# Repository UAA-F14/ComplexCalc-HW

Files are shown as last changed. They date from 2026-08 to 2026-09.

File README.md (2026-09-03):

# ComplexCalc — Hardware Version 🔌⚡

**A standalone embedded calculator for complex n×n linear systems (Ax=b)** — no PC required at runtime. Custom STM32F411 PCB with a 16-button keypad and an ILI9341 TFT display, built for electronics students and AC circuit analysis.

> [!NOTE]
> **Work in progress.** Firmware is functional (keypad input, TFT UI, Gauss-Jordan solver); the PCB is still being routed (some ADC connections are pending — see [Design](#-design-pcb)).

---

## 📁 Repository Structure

```
├── code/
│   └── 06ComplexCalcDasProject/   # STM32CubeIDE / CMake firmware project
│       ├── Core/
│       │   ├── Inc/               # ComplexGJ.h (solver), TFT_Screen.h, display_ui.h, ...
│       │   └── Src/                # SWComplexGJ.c (solver), TFT_Screen.c, display_ui.c, main.c, ...
│       └── Drivers/                # Vendored STM32 HAL + CMSIS (ST-generated, not project code)
├── design/
│   └── ComplexCalc/                # KiCad schematic + PCB (in progress)
└── README.md
```

The actual project logic lives in `Core/Inc` / `Core/Src`; everything under `Drivers/` is STM32CubeMX-generated boilerplate.

---

## 🎯 Overview

- **MCU:** STM32F411C(C/E)U (Cortex-M4, UFQFPN48) — the same chip used on "BlackPill" dev boards, but here on a custom PCB, you can use the minimum sistem or insert a blackpill in the socket, it works either way.
- **Display:** ILI9341 TFT over SPI.
- **Input:** 16-button matrix keypad (4×4), wired directly on the PCB.
- **Power:** coin-cell battery holder + AMS1117-3.3 LDO regulator.
- **Solver:** Gauss-Jordan elimination, single-precision (`float`) complex arithmetic, systems from 2×2 up to 4×4.

No serial terminal, USB host, or PC connection is needed to use the calculator — power it on, and the keypad + screen are the whole interface. (USB/SWD is only used to flash firmware.)

---

## 🚀 Build & Flash

**Using STM32CubeIDE (recommended):**
1. Open STM32CubeIDE.
2. File → Open Projects from File System.
3. Select `code/06ComplexCalcDasProject/`.
4. Build (`Ctrl+B`), then flash over USB/SWD (`Ctrl+Alt+X`).

**Using CMake + the ARM GCC toolchain (also supported by this project):**
```bash
cd code/06ComplexCalcDasProject
cmake --preset Debug      # or: Release
cmake --build --build-preset Debug
```
This uses the project's own `cmake/gcc-arm-none-eabi.cmake` toolchain file — you'll need `arm-none-eabi-gcc` and `ninja` installed.

---

## 🎮 Usage

On power-up, the screen prompts for the system size (`2`–`4`). From there:

| Input | Action |
|---|---|
| `0`–`9` | Enter digits (toggles between real/imaginary part) |
| `=` | Confirm entry / advance |
| `S` + `P` (combo) | Cycle display theme |

Once the full A matrix and b vector are entered, the solver runs on-device and the result is shown on screen — no PC needed.

---

## 🧮 Solver Details

- **Algorithm:** Gauss-Jordan elimination (`solve_complex_system` in `ComplexGJ.h`/`SWComplexGJ.c`).
- **Precision:** single-precision float, `EPSILON = 1e-7` for singularity checks.
- **Maximum size:** 4×4 (`N_MAX`), matching the keypad-driven size range (2–4).
- **Error handling:** returns `SOLVER_ERR_INVALID_SIZE` / `SOLVER_ERR_SINGULAR` for out-of-range sizes or singular matrices.

---

## 🖥️ Design (PCB)

KiCad project at `design/ComplexCalc/` — schematic + PCB for the keypad, MCU, TFT header, and power circuitry.

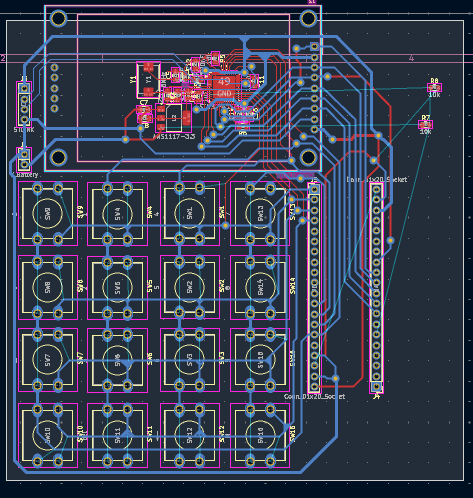
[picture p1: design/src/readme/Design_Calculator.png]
PCB routing in progress


*Routing in progress — some ADC-related connections are still pending. A rendered board image will replace this screenshot once the layout is finished.*

A datasheet-vs-schematic power supply review (VCAP sizing, VBAT, NRST, HSE crystal value) is available at [`docs/ComplexCalc-HW_power_supply_review_en.pdf`](docs/ComplexCalc-HW_power_supply_review_en.pdf) ([Spanish version](docs/ComplexCalc-HW_power_supply_review.pdf)).

---

## 🤝 Contributing

1. Firmware changes go in `code/06ComplexCalcDasProject/Core/`.
2. PCB changes go in `design/ComplexCalc/` (KiCad 8+).
3. Open a PR against this repo.

## 📞 Issues

Report bugs or hardware questions via this repo's [Issues](https://github.com/UAA-F14/ComplexCalc-HW/issues).

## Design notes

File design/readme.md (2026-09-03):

# Design

## Collaborators

- **das** — base layout and initial design.
- **robertoloro** — routing the rest of the board.
- **IKGB** — checking and validating the minimum system.

# Logfile
## 8-28

Pending to connect multiple veins of minimum system.

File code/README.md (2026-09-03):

# Code

Firmware for the STM32F411CEUx (`06ComplexCalcDasProject/`, STM32CubeIDE / CMake project).

## Collaborators

- **das** — wrote the firmware (keypad input, TFT UI, Gauss-Jordan solver).

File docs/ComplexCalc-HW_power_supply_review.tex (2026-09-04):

\documentclass[11pt]{article}
\usepackage[margin=2.5cm]{geometry}
\usepackage[utf8]{inputenc}
\usepackage[T1]{fontenc}
\usepackage{graphicx}
\usepackage{booktabs}
\usepackage{longtable}
\usepackage{xcolor}
\usepackage{hyperref}
\usepackage{siunitx}
\usepackage{caption}
\hypersetup{colorlinks=false, pdfborder={0 0 0}}

\renewcommand{\figurename}{Figura}
\renewcommand{\tablename}{Tabla}
\renewcommand{\contentsname}{Índice}

\definecolor{okgreen}{RGB}{0,120,60}
\definecolor{warnred}{RGB}{180,30,30}
\definecolor{sugamber}{RGB}{170,110,0}

\title{ComplexCalc-HW — Revisión del esquema de alimentación}
\author{}
\date{}

\begin{document}
\maketitle
\vspace{-1.3cm}

\section{Propósito}

Este documento resume los requisitos oficiales de alimentación del
STM32F411CEUx (datasheet DocID026289 Rev.\,7, ST\-Microelectronics) para el
paquete \textbf{UFQFPN48}, y los compara contra lo que actualmente está
routeado en \texttt{design/\allowbreak ComplexCalc/\allowbreak
ComplexCalc.kicad\_sch} del repositorio
\texttt{UAA-F14/\allowbreak ComplexCalc-HW}. Todas las figuras y tablas de referencia son
capturas directas del datasheet oficial.

\section{Pinout real: UFQFPN48}

La Figura~\ref{fig:pinout} (Figura~10 del datasheet, página~34) muestra la
asignación exacta de pines del paquete que se usa en esta placa. De ahí se
confirma:

\begin{itemize}
  \item \textbf{3 pines VDD}: 24, 36, 48
  \item \textbf{3 pines VSS}: 23, 35, 47
  \item \textbf{1 solo pin VCAP\_1} (pin 22) — este paquete \emph{no} trae
        VCAP\_2 (esa señal solo existe en LQFP100 y UFBGA100)
  \item VBAT: pin 1
  \item VDDA/VREF+: pin 9 · VSSA/VREF-: pin 8
  \item NRST: pin 7 · BOOT0: pin 44
\end{itemize}

\begin{figure}[h]
  \centering
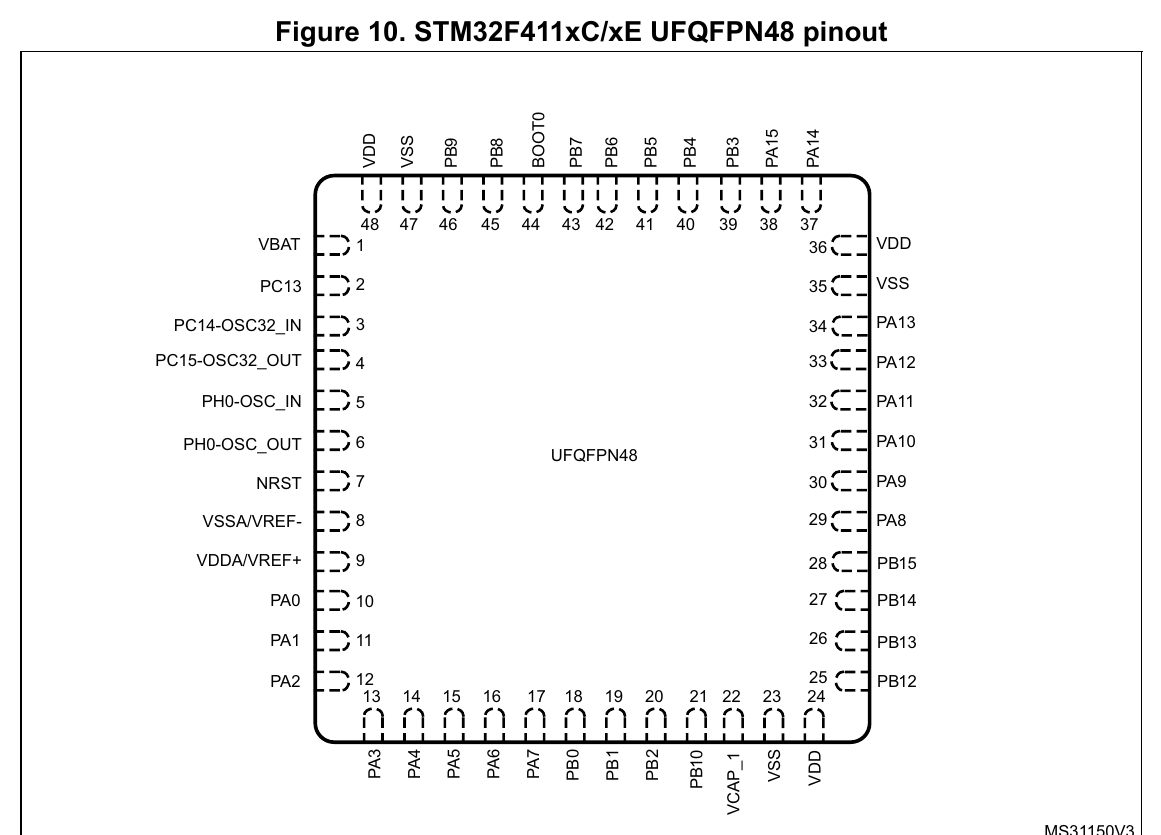
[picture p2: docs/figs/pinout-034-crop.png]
  
  \caption{Pinout UFQFPN48 — Figura 10, datasheet STM32F411xC/xE, pág.~34}
  \label{fig:pinout}
\end{figure}

\clearpage
\section{Esquema oficial de alimentación}

La Figura~\ref{fig:powerscheme} (Figura~17, Sección 6.1.6, página~59) es el
esquema de referencia de ST para el desacoplo de cada rama de alimentación.

\begin{figure}[h]
  \centering
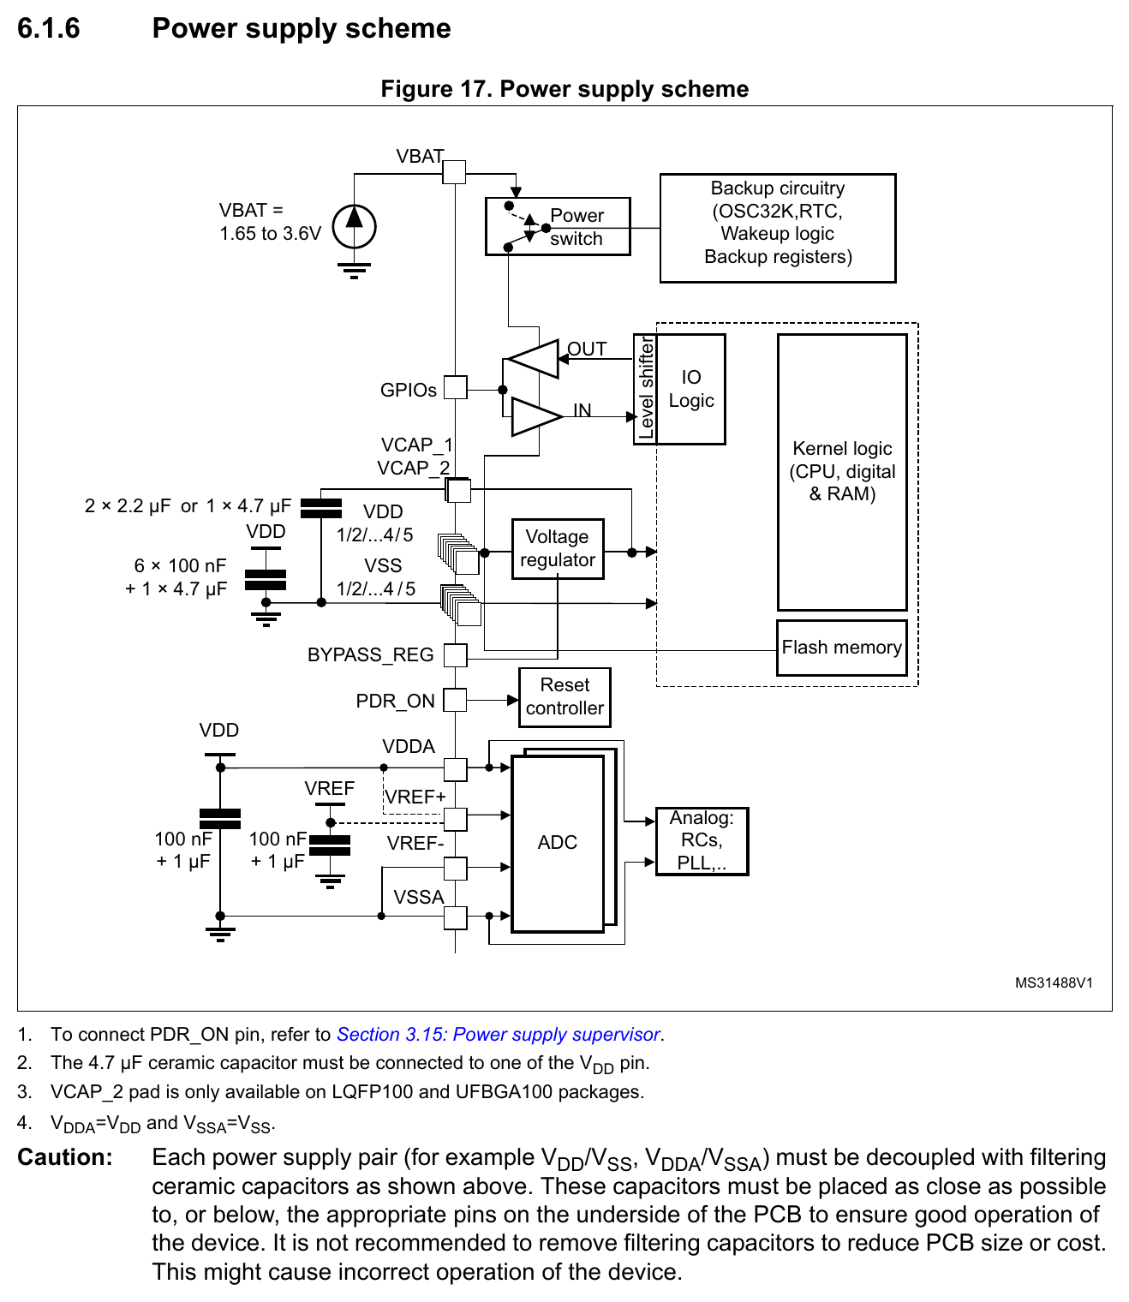
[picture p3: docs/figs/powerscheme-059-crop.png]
  
  \caption{Power supply scheme — Figura 17, Sección 6.1.6, pág.~59}
  \label{fig:powerscheme}
\end{figure}

\newpage
\section{Capacitor de VCAP para paquetes de un solo pin}

La Tabla~\ref{fig:vcaptable} (Tabla~16, Sección 6.3.2, página~65) da el valor
exacto que aplica específicamente cuando el paquete solo trae un pin VCAP
(nuestro caso).

\begin{figure}[h]
  \centering
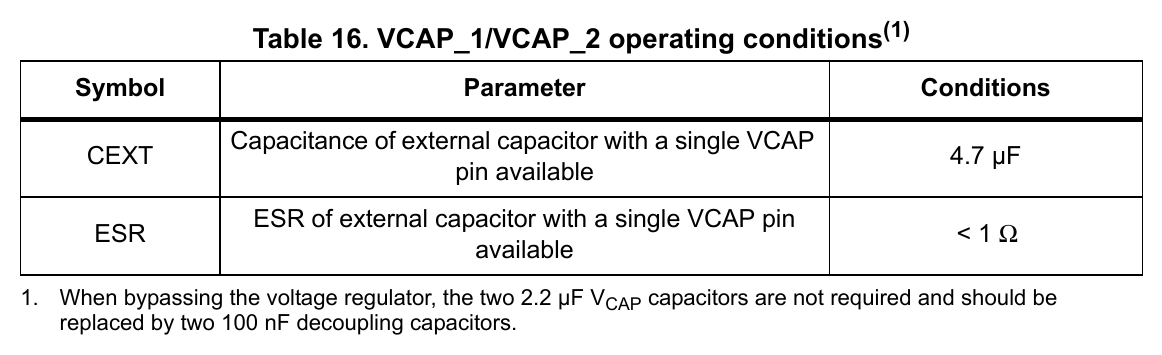
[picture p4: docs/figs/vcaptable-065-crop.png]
  
  \caption{VCAP\_1/VCAP\_2 operating conditions — Tabla 16, Sección 6.3.2, pág.~65}
  \label{fig:vcaptable}
\end{figure}

\section{Resumen: valores requeridos por pin}

\begin{longtable}{p{3.2cm}p{4.5cm}p{6cm}}
\toprule
\textbf{Pin(es)} & \textbf{Capacitor(es) requerido(s)} & \textbf{Fuente} \\
\midrule
\endhead
VDD / VSS (pines 24/23, 36/35, 48/47) &
  100\,nF por cada par VDD/VSS (3 en total) + 1$\times$4.7\,µF en cualquiera
  de los VDD &
  Figura~17, nota~2 \\
VCAP\_1 (pin 22) $\rightarrow$ GND &
  \textbf{4.7\,µF cerámico, ESR $<$ 1\,$\Omega$} (paquete de un solo VCAP) &
  Tabla~16, Sección~6.3.2 \\
VDDA/VREF+ (pin 9) $\leftrightarrow$ VSSA/VREF- (pin 8) &
  100\,nF + 1\,µF (un solo par: en este paquete VDDA y VREF+ comparten pin) &
  Figura~17 \\
VBAT (pin 1) &
  100\,nF, o conexión directa a VDD si no se usa batería de respaldo &
  Figura~17 \\
NRST (pin 7) &
  Ya trae pull-up interno — capacitor externo (100\,nF, opcional) solo
  mejora inmunidad a EMI, no es obligatorio &
  Tabla~7 (leyenda NRST) \\
BOOT0 (pin 44) &
  Sin bias interno — resistencia externa (típico 10\,k$\Omega$ pull-down
  para bootear de flash) &
  Sección 3.13 ``Boot modes'' \\
\bottomrule
\end{longtable}

\clearpage
\section{Comparación contra lo routeado en el esquemático real}

Extraído del netlist de \texttt{ComplexCalc.kicad\_sch} (exportado con
\texttt{kicad-cli}) el 2 de septiembre de 2026.

\begin{longtable}{p{3.5cm}p{3.2cm}p{3.2cm}p{4cm}}
\toprule
\textbf{Punto revisado} & \textbf{Requerido} & \textbf{En el esquemático} & \textbf{Veredicto} \\
\midrule
\endhead
VCAP\_1 (C14) & 4.7\,µF, ESR$<$1$\Omega$ & \textbf{2.2\,µF} &
  \textcolor{warnred}{\textbf{Por debajo del valor requerido}} — 2.2\,µF es el
  valor para paquetes con \emph{dos} pines VCAP, no uno solo. \\
VBAT (pin 1) & Atado a batería o a VDD & \textbf{Sin conexión (net aislada)} &
  \textcolor{warnred}{\textbf{Flotando}} — no está ni en el net de 3.3V ni tiene
  capacitor. \\
VDD/VSS (3 pares) & 3$\times$100\,nF + 1 bulk & C10, C11, C12 (100\,nF c/u)
  + C13 (1\,µF) + C8 (22\,µF) & \textcolor{okgreen}{Cumple} — bulk incluso más
  grande de lo mínimo pedido. \\
VDDA/VREF+ (pin 9) & 100\,nF + 1\,µF local & Mismo net de 3.3\,V que VDD,
  con C13 (1\,µF) presente & \textcolor{okgreen}{Cumple eléctricamente} — no se
  pudo verificar cercanía física del capacitor al pin desde el esquemático
  (revisar en el layout). \\
NRST & Pull-up interno ya suficiente; cap.\ típico 100\,nF & R4 (10\,k$\Omega$
  externo, redundante) + C9 (\textbf{1\,µF}, no 100\,nF) &
  \textcolor{sugamber}{\textbf{Sugerido bajar a 100\,nF}} — no es un error
  (sigue siendo funcional), pero 1\,µF alarga el tiempo de reset más de lo
  necesario. Confirmado contra el esquemático real del BlackPill (WeAct
  Studio): su circuito de reset usa exactamente \textbf{100\,nF} en el mismo
  nodo. \\
BOOT0 (R5) & Pull-down $\sim$10\,k$\Omega$ & 10\,k$\Omega$ &
  \textcolor{okgreen}{Correcto} \\
BOOT1/PB2 (R6) & Definir nivel & 10\,k$\Omega$ pull &
  \textcolor{okgreen}{Correcto} \\
Cristal HSE (Y1) & Coincidir con \texttt{RCC.HSE\_VALUE} en firmware &
  Y1 = \textbf{8\,MHz} físico, pero el \texttt{.ioc} tiene
  \texttt{HSE\_VALUE=25000000} & \textcolor{warnred}{\textbf{Revisar}} — si el
  firmware llega a habilitar HSE, el árbol de reloj debe recalcularse para
  8\,MHz, no 25\,MHz. \\
Regulador (U2) & --- & \textbf{AMS1117-3.3} (no NCP1117-3.3) &
  Nota de documentación: corregido en el README del repo. \\
\bottomrule
\end{longtable}

\section{Acciones recomendadas}

\begin{enumerate}
  \item Cambiar C14 de 2.2\,µF a \textbf{4.7\,µF} en VCAP\_1.
        \textcolor{okgreen}{\textbf{[Hecho]}} --- verificado en el netlist
        actual del esquemático: C14 = 4.7\,µF.
  \item Conectar VBAT (pin 1) a la red de 3.3\,V (o dejar un footprint de
        100\,nF si en el futuro se agrega batería de respaldo real para el
        RTC).
        \textcolor{okgreen}{\textbf{[Hecho]}} --- verificado: VBAT (U3
        pin~1) ahora está en el net \texttt{3.3V}.
  \item Bajar C9 (NRST) de 1\,µF a \textbf{100\,nF} — valor de libro y el que
        usa el BlackPill real de referencia en el mismo nodo.
        \textcolor{okgreen}{\textbf{[Hecho]}} --- verificado: C9 = 100\,nF.
  \item Antes de habilitar el HSE en firmware, corregir
        \texttt{RCC.HSE\_VALUE} a 8\,MHz en el \texttt{.ioc} y regenerar el
        árbol de reloj en STM32CubeMX.
  \item Verificar en el layout físico (no solo el esquemático) que los
        capacitores de VDD/VDDA queden lo más cerca posible de sus pines
        respectivos, dado que la capa inferior ya está ocupada por el
        teclado matricial.
\end{enumerate}

\end{document}

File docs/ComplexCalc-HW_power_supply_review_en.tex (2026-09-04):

\documentclass[11pt]{article}
\usepackage[margin=2.5cm]{geometry}
\usepackage[utf8]{inputenc}
\usepackage[T1]{fontenc}
\usepackage{graphicx}
\usepackage{booktabs}
\usepackage{longtable}
\usepackage{xcolor}
\usepackage{hyperref}
\usepackage{siunitx}
\usepackage{caption}
\hypersetup{colorlinks=false, pdfborder={0 0 0}}

\definecolor{okgreen}{RGB}{0,120,60}
\definecolor{warnred}{RGB}{180,30,30}
\definecolor{sugamber}{RGB}{170,110,0}

\title{ComplexCalc-HW --- Power Supply Review}
\author{}
\date{}

\begin{document}
\maketitle
\vspace{-1.3cm}

\section{Purpose}

This document summarizes the official power supply requirements of the
STM32F411CEUx (datasheet DocID026289 Rev.\,7, ST\-Microelectronics) for the
\textbf{UFQFPN48} package, and compares them against what is currently
routed in \texttt{design/\allowbreak ComplexCalc/\allowbreak
ComplexCalc.kicad\_sch} of the \texttt{UAA-F14/\allowbreak ComplexCalc-HW}
repository. All reference figures and tables are direct captures from the
official datasheet.

\section{Actual pinout: UFQFPN48}

Figure~\ref{fig:pinout} (Figure~10 of the datasheet, page~34) shows the
exact pin assignment of the package used on this board. From it we
confirm:

\begin{itemize}
  \item \textbf{3 VDD pins}: 24, 36, 48
  \item \textbf{3 VSS pins}: 23, 35, 47
  \item \textbf{Only 1 VCAP\_1 pin} (pin 22) --- this package does
        \emph{not} bring out VCAP\_2 (that signal only exists on the
        LQFP100 and UFBGA100 packages)
  \item VBAT: pin 1
  \item VDDA/VREF+: pin 9 · VSSA/VREF-: pin 8
  \item NRST: pin 7 · BOOT0: pin 44
\end{itemize}

\begin{figure}[h]
  \centering
  
  \caption{UFQFPN48 pinout --- Figure 10, STM32F411xC/xE datasheet, p.~34}
  \label{fig:pinout}
\end{figure}

\clearpage
\section{Official power supply scheme}

Figure~\ref{fig:powerscheme} (Figure~17, Section 6.1.6, page~59) is ST's
reference scheme for decoupling each power supply branch.

\begin{figure}[h]
  \centering
  
  \caption{Power supply scheme --- Figure 17, Section 6.1.6, p.~59}
  \label{fig:powerscheme}
\end{figure}

\newpage
\section{VCAP capacitor for single-pin packages}

Table~\ref{fig:vcaptable} (Table~16, Section 6.3.2, page~65) gives the
exact value that applies specifically when the package brings out only one
VCAP pin (our case).

\begin{figure}[h]
  \centering
  
  \caption{VCAP\_1/VCAP\_2 operating conditions --- Table 16, Section 6.3.2, p.~65}
  \label{fig:vcaptable}
\end{figure}

\section{Summary: required values per pin}

\begin{longtable}{p{3.2cm}p{4.5cm}p{6cm}}
\toprule
\textbf{Pin(s)} & \textbf{Required capacitor(s)} & \textbf{Source} \\
\midrule
\endhead
VDD / VSS (pins 24/23, 36/35, 48/47) &
  100\,nF per VDD/VSS pair (3 total) + 1$\times$4.7\,µF on any of the
  VDD pins &
  Figure~17, note~2 \\
VCAP\_1 (pin 22) $\rightarrow$ GND &
  \textbf{4.7\,µF ceramic, ESR $<$ 1\,$\Omega$} (single-VCAP package) &
  Table~16, Section~6.3.2 \\
VDDA/VREF+ (pin 9) $\leftrightarrow$ VSSA/VREF- (pin 8) &
  100\,nF + 1\,µF (single pair: on this package VDDA and VREF+ share a
  pin) &
  Figure~17 \\
VBAT (pin 1) &
  100\,nF, or a direct connection to VDD if no backup battery is used &
  Figure~17 \\
NRST (pin 7) &
  Already has an internal pull-up --- an external capacitor (100\,nF,
  optional) only improves EMI immunity, it is not mandatory &
  Table~7 (NRST legend) \\
BOOT0 (pin 44) &
  No internal bias --- external resistor (typ. 10\,k$\Omega$ pull-down
  to boot from flash) &
  Section 3.13 ``Boot modes'' \\
\bottomrule
\end{longtable}

\clearpage
\section{Comparison against the actual schematic}

Extracted from the \texttt{ComplexCalc.kicad\_sch} netlist (exported with
\texttt{kicad-cli}) on September 2, 2026.

\begin{longtable}{p{3.5cm}p{3.2cm}p{3.2cm}p{4cm}}
\toprule
\textbf{Checked item} & \textbf{Required} & \textbf{In the schematic} & \textbf{Verdict} \\
\midrule
\endhead
VCAP\_1 (C14) & 4.7\,µF, ESR$<$1$\Omega$ & \textbf{2.2\,µF} &
  \textcolor{warnred}{\textbf{Below the required value}} --- 2.2\,µF is
  the value for packages with \emph{two} VCAP pins, not a single one. \\
VBAT (pin 1) & Tied to battery or to VDD & \textbf{Unconnected (isolated
  net)} & \textcolor{warnred}{\textbf{Floating}} --- it is neither on the
  3.3\,V net nor does it have a capacitor. \\
VDD/VSS (3 pairs) & 3$\times$100\,nF + 1 bulk & C10, C11, C12 (100\,nF
  each) + C13 (1\,µF) + C8 (22\,µF) &
  \textcolor{okgreen}{Meets the requirement} --- bulk capacitance is even
  larger than the minimum required. \\
VDDA/VREF+ (pin 9) & 100\,nF + 1\,µF local & Same 3.3\,V net as VDD, with
  C13 (1\,µF) present & \textcolor{okgreen}{Electrically compliant} ---
  physical proximity of the capacitor to the pin could not be verified
  from the schematic (check the layout). \\
NRST & Internal pull-up already sufficient; typ.\ cap.\ 100\,nF & R4
  (10\,k$\Omega$ external, redundant) + C9 (\textbf{1\,µF}, not 100\,nF) &
  \textcolor{sugamber}{\textbf{Suggest lowering to 100\,nF}} --- not an
  error (it is still functional), but 1\,µF extends the reset time more
  than necessary. Confirmed against the actual BlackPill schematic (WeAct
  Studio): its reset circuit uses exactly \textbf{100\,nF} at the same
  node. \\
BOOT0 (R5) & $\sim$10\,k$\Omega$ pull-down & 10\,k$\Omega$ &
  \textcolor{okgreen}{Correct} \\
BOOT1/PB2 (R6) & Define level & 10\,k$\Omega$ pull &
  \textcolor{okgreen}{Correct} \\
HSE crystal (Y1) & Must match \texttt{RCC.HSE\_VALUE} in firmware &
  Y1 = \textbf{8\,MHz} physically, but the \texttt{.ioc} has
  \texttt{HSE\_VALUE=25000000} & \textcolor{warnred}{\textbf{Review}} ---
  if the firmware ever enables HSE, the clock tree must be recalculated
  for 8\,MHz, not 25\,MHz. \\
Regulator (U2) & --- & \textbf{AMS1117-3.3} (not NCP1117-3.3) &
  Documentation note: corrected in the repo's README. \\
\bottomrule
\end{longtable}

\section{Recommended actions}

\begin{enumerate}
  \item Change C14 from 2.2\,µF to \textbf{4.7\,µF} on VCAP\_1.
        \textcolor{okgreen}{\textbf{[Done]}} --- verified in the current
        schematic netlist: C14 = 4.7\,µF.
  \item Connect VBAT (pin 1) to the 3.3\,V rail (or leave a 100\,nF
        footprint if a real backup battery for the RTC is added in the
        future).
        \textcolor{okgreen}{\textbf{[Done]}} --- verified: VBAT (U3 pin~1)
        is now on the \texttt{3.3V} net.
  \item Lower C9 (NRST) from 1\,µF to \textbf{100\,nF} --- the textbook
        value, and the one used by the actual reference BlackPill at the
        same node.
        \textcolor{okgreen}{\textbf{[Done]}} --- verified: C9 = 100\,nF.
  \item Before enabling HSE in firmware, correct \texttt{RCC.HSE\_VALUE}
        to 8\,MHz in the \texttt{.ioc} and regenerate the clock tree in
        STM32CubeMX.
  \item Verify on the physical layout (not just the schematic) that the
        VDD/VDDA capacitors are placed as close as possible to their
        respective pins, since the bottom layer is already occupied by
        the matrix keypad.
\end{enumerate}

\end{document}

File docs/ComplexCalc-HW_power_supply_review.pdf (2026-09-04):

## ComplexCalc-HW — Revisión del esquema de alimentación

### 1 Propósito

Este documento resume los requisitos oficiales de alimentación del STM32F411CEUx (datasheet DocID026289 Rev. 7, STMicroelectronics) para el paquete UFQFPN48, y los compara contra lo que actualmente está routeado en design/ComplexCalc/ComplexCalc.kicad_sch del repositorio UAA-F14/ ComplexCalc-HW. Todas las figuras y tablas de referencia son capturas directas del datasheet oficial.

### 2 Pinout real: UFQFPN48

La Figura 1 (Figura 10 del datasheet, página 34) muestra la asignación exacta de pines del paquete que se usa en esta placa. De ahí se confirma:

- 3 pines VDD: 24, 36, 48
- 3 pines VSS: 23, 35, 47
- 1 solo pin VCAP_1 (pin 22) — este paquete no trae VCAP_2 (esa señal solo existe en LQFP100 y UFBGA100)
- VBAT: pin 1
- VDDA/VREF+: pin 9 · VSSA/VREF-: pin 8
- NRST: pin 7 · BOOT0: pin 44


Figura 1: Pinout UFQFPN48 — Figura 10, datasheet STM32F411xC/xE, pág. 34

### 3 Esquema oficial de alimentación

La Figura 2 (Figura 17, Sección 6.1.6, página 59) es el esquema de referencia de ST para el desacoplo de cada rama de alimentación.


Figura 2: Power supply scheme — Figura 17, Sección 6.1.6, pág. 59

### 4 Capacitor de VCAP para paquetes de un solo pin

La Tabla 3 (Tabla 16, Sección 6.3.2, página 65) da el valor exacto que aplica específicamente cuando el paquete solo trae un pin VCAP (nuestro caso).

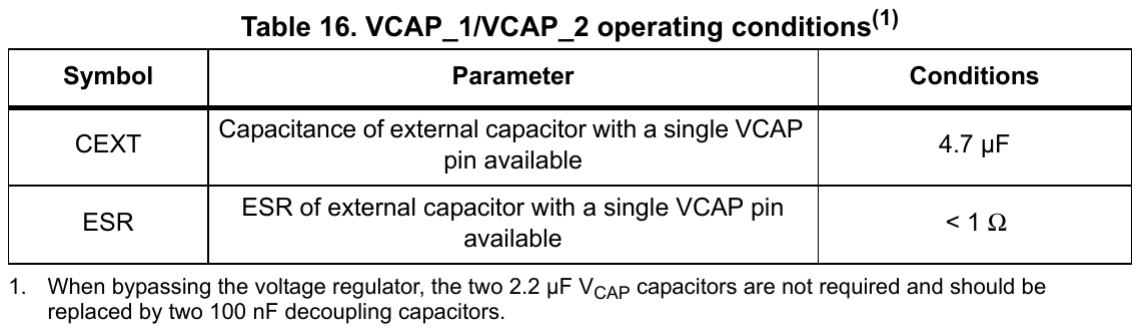
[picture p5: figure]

Figura 3: VCAP_1/VCAP_2 operating conditions — Tabla 16, Sección 6.3.2, pág. 65

### 5 Resumen: valores requeridos por pin

Pin(es) | Capacitor(es) | re-
querido(s)

Fuente

VDD / VSS (pines
24/23, | 36/35,
48/47)
100 nF | por | cada | par
VDD/VSS (3 en total) +
1×4.7 µF en cualquiera de
los VDD

Figura 17, nota 2

VCAP_1 (pin 22)
→ GND

### 4.7 µF cerámico, ESR < 1 Ω (paquete de un solo

VCAP)

Tabla 16, Sección 6.3.2

VDDA/VREF+
(pin | 9) | ↔
VSSA/VREF-
(pin 8)

100 nF + 1 µF (un solo par: en este paquete VDDA y
VREF+ comparten pin)

Figura 17

VBAT (pin 1) | 100 nF, o conexión directa a VDD si no se usa batería de respaldo
Figura 17
NRST (pin 7) | Ya trae pull-up interno — capacitor externo (100 nF, opcional) solo mejora in- munidad a EMI, no es obli- gatorio

Tabla 7 (leyenda NRST)

BOOT0 (pin 44) Sin bias interno — resisten- cia externa (típico 10 kΩ pull-down para bootear de flash)Sección 3.13 “Boot modes”

### 6 Comparación contra lo routeado en el esquemático real

Extraído del netlist de ComplexCalc.kicad_sch (exportado con kicad-cli) el 2 de septiembre de 2026.

Punto revisado | Requerido | En | el | es-
quemático

Veredicto

VCAP_1 (C14) | 4.7 µF, ESR<1Ω | 2.2 µF | Por debajo del valor
requerido — 2.2 µF es
el valor para paquetes
con dos pines VCAP, no
uno solo.
VBAT (pin 1) | Atado a batería o a
| VDD
Sin | conexión
(net aislada)

Flotando — no está ni
en el net de 3.3V ni tiene capacitor.
VDD/VSS (3 pares) | 3×100 nF + 1 bulk | C10, | C11, | C12
| | (100 nF | c/u) | +
C13 (1 µF) + C8
| | (22 µF)

Cumple — bulk incluso
más grande de lo mínimo pedido.

VDDA/VREF+ (pin
9)

100 nF + 1 µF local Mismo net de 3.3 V que VDD, con C13
(1 µF) presente

Cumple eléctricamente
— no se pudo verificar
cercanía física del capacitor al pin desde el
esquemático (revisar en
el layout).
NRST | Pull-up | interno
| ya suficiente; cap.
| típico 100 nF

R4 (10 kΩ externo,
redundante) + C9
(1 µF, no 100 nF)
Sugerido | bajar | a
100 nF — no es un
error | (sigue | siendo
funcional), pero 1 µF
alarga el tiempo de reset más de lo necesario.
Confirmado | contra
el | esquemático | real
del BlackPill (WeAct
Studio): su circuito de
reset usa exactamente
100 nF en el mismo
nodo.
BOOT0 (R5) | Pull-down ∼10 kΩ | 10 kΩ | Correcto
BOOT1/PB2 (R6) | Definir nivel | 10 kΩ pull | Correcto
Cristal HSE (Y1) | Coincidir | con
| RCC.HSE_VALUE en
| firmware
Y1 | = | 8 MHz
| | físico, | | pero
| | el | .ioc | tiene
HSE_VALUE=25000000
Revisar | — | si | el
firmware llega a habilitar HSE, el árbol de
reloj debe recalcularse
para 8 MHz, no 25 MHz.

Punto revisado | Requerido | En | el | es-
quemático

Veredicto

Regulador (U2) | — | AMS1117-3.3
(no NCP1117-3.3)

Nota de documentación:
corregido | en | el
README del repo.

### 7 Acciones recomendadas

1. Cambiar C14 de 2.2 µF a 4.7 µF en VCAP_1. [Hecho] — verificado en el netlist actual del esquemático: C14 = 4.7 µF.
2. Conectar VBAT (pin 1) a la red de 3.3 V (o dejar un footprint de 100 nF si en el futuro se agrega batería de respaldo real para el RTC). [Hecho] — verificado: VBAT (U3 pin 1) ahora está en el net 3.3V.
3. Bajar C9 (NRST) de 1 µF a 100 nF — valor de libro y el que usa el BlackPill real de referencia en el mismo nodo. [Hecho] — verificado: C9 = 100 nF.
4. Antes de habilitar el HSE en firmware, corregir RCC.HSE_VALUE a 8 MHz en el .ioc y regenerar el árbol de reloj en STM32CubeMX.
5. Verificar en el layout físico (no solo el esquemático) que los capacitores de VDD/VDDA queden lo más cerca posible de sus pines respectivos, dado que la capa inferior ya está ocupada por el teclado matricial.

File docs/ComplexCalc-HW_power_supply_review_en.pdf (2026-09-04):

## ComplexCalc-HW — Power Supply Review

### 1 Purpose

This document summarizes the official power supply requirements of the STM32F411CEUx (datasheet DocID026289 Rev. 7, STMicroelectronics) for the UFQFPN48 package, and compares them against
what is currently routed in design/ComplexCalc/ComplexCalc.kicad_sch of the UAA-F14/ComplexCalc-HW repository. All reference figures and tables are direct captures from the official datasheet.

### 2 Actual pinout: UFQFPN48

Figure 1 (Figure 10 of the datasheet, page 34) shows the exact pin assignment of the package used on this board. From it we confirm:

- 3 VDD pins: 24, 36, 48
- 3 VSS pins: 23, 35, 47
- Only 1 VCAP_1 pin (pin 22) — this package does not bring out VCAP_2 (that signal only exists on the LQFP100 and UFBGA100 packages)
- VBAT: pin 1
- VDDA/VREF+: pin 9 · VSSA/VREF-: pin 8
- NRST: pin 7 · BOOT0: pin 44


Figure 1: UFQFPN48 pinout — Figure 10, STM32F411xC/xE datasheet, p. 34

### 3 Official power supply scheme

Figure 2 (Figure 17, Section 6.1.6, page 59) is ST’s reference scheme for decoupling each power supply branch.


Figure 2: Power supply scheme — Figure 17, Section 6.1.6, p. 59

### 4 VCAP capacitor for single-pin packages

Table 3 (Table 16, Section 6.3.2, page 65) gives the exact value that applies specifically when the package brings out only one VCAP pin (our case).


Figure 3: VCAP_1/VCAP_2 operating conditions — Table 16, Section 6.3.2, p. 65

### 5 Summary: required values per pin

Pin(s) | Required capacitor(s) | Source

VDD / VSS (pins
24/23, | 36/35,
48/47) | 100 nF per VDD/VSS pair (3 total) + 1×4.7 µF on any of the VDD pins
Figure 17, note 2

VCAP_1 (pin 22)
→ GND

### 4.7 µF ceramic, ESR

< 1 Ω (single-VCAP package)

Table 16, Section 6.3.2

VDDA/VREF+
(pin | 9) | ↔
VSSA/VREF-
(pin 8)

100 nF + 1 µF (single pair: on this package VDDA and
VREF+ share a pin)

Figure 17

VBAT (pin 1) | 100 nF, or a direct connec- tion to VDD if no backup battery is used
Figure 17
NRST (pin 7) | Already has an internal pull-up — an external ca- pacitor (100 nF, optional) only improves EMI immu- nity, it is not mandatory

Table 7 (NRST legend)

BOOT0 (pin 44) No internal bias — external resistor (typ. 10 kΩ pull- down to boot from flash) Section 3.13 “Boot modes”

### 6 Comparison against the actual schematic

Extracted from the ComplexCalc.kicad_sch netlist (exported with kicad-cli) on September 2, 2026.

Checked item | Required | In the schematic | Verdict
VCAP_1 (C14) | 4.7 µF, ESR<1Ω | 2.2 µF | Below the required
value — 2.2 µF is the
value for packages with
two VCAP pins, not a
single one.
VBAT (pin 1) | Tied to battery or to VDD
Unconnected
(isolated net)

Floating — it is neither on the 3.3 V net nor
does it have a capacitor.
VDD/VSS (3 pairs) | 3×100 nF + 1 bulk | C10, | C11, | C12
(100 nF each) +
C13 (1 µF) + C8
| | (22 µF)

Meets the requirement
— bulk capacitance is
even larger than the
minimum required.
VDDA/VREF+ (pin
9)

100 nF + 1 µF local Same 3.3 V net as VDD, with C13
(1 µF) present

Electrically compliant
— physical proximity of
the capacitor to the pin
could not be verified
from | the | schematic
(check the layout).
NRST | Internal | pull-up
| already sufficient; typ. cap. 100 nF

R4 (10 kΩ external,
redundant) + C9
(1 µF, not 100 nF)

Suggest lowering to
100 nF — not an error
(it is still functional),
but 1 µF extends the
reset time more than
necessary. | Confirmed
against | the | actual
BlackPill | schematic
(WeAct Studio): its reset circuit uses exactly
100 nF at the same
node.
BOOT0 (R5) | ∼10 kΩ pull-down | 10 kΩ | Correct
BOOT1/PB2 (R6) | Define level | 10 kΩ pull | Correct
HSE crystal (Y1) | Must | match
| RCC.HSE_VALUE in firmware
Y1 | = | 8 MHz
physically, | but
| | the | .ioc | has
HSE_VALUE=25000000
Review | — | if | the
firmware ever enables
HSE, the clock tree
must be recalculated for
8 MHz, not 25 MHz.
Regulator (U2) | — | AMS1117-3.3
(not NCP1117-3.3)

Documentation note:
corrected in the repo’s
README.

### 7 Recommended actions

1. Change C14 from 2.2 µF to 4.7 µF on VCAP_1. [Done] — verified in the current schematic netlist: C14 = 4.7 µF.
2. Connect VBAT (pin 1) to the 3.3 V rail (or leave a 100 nF footprint if a real backup battery for the RTC is added in the future). [Done] — verified: VBAT (U3 pin 1) is now on the 3.3V net.
3. Lower C9 (NRST) from 1 µF to 100 nF — the textbook value, and the one used by the actual reference BlackPill at the same node. [Done] — verified: C9 = 100 nF.
4. Before enabling HSE in firmware, correct RCC.HSE_VALUE to 8 MHz in the .ioc and regenerate the clock tree in STM32CubeMX.
5. Verify on the physical layout (not just the schematic) that the VDD/VDDA capacitors are placed as close as possible to their respective pins, since the bottom layer is already occupied by the matrix keypad.

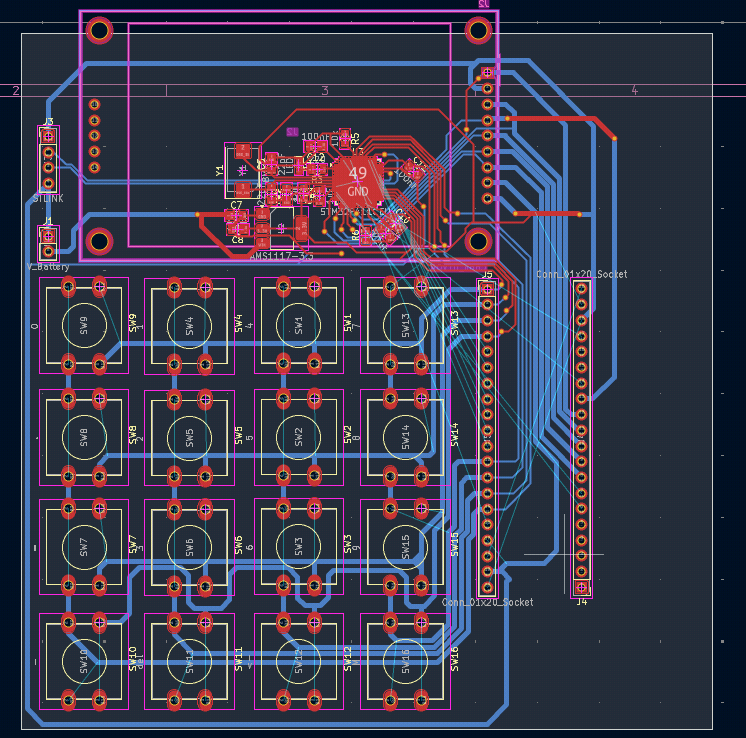
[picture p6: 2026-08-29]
design/src/readme/image.png

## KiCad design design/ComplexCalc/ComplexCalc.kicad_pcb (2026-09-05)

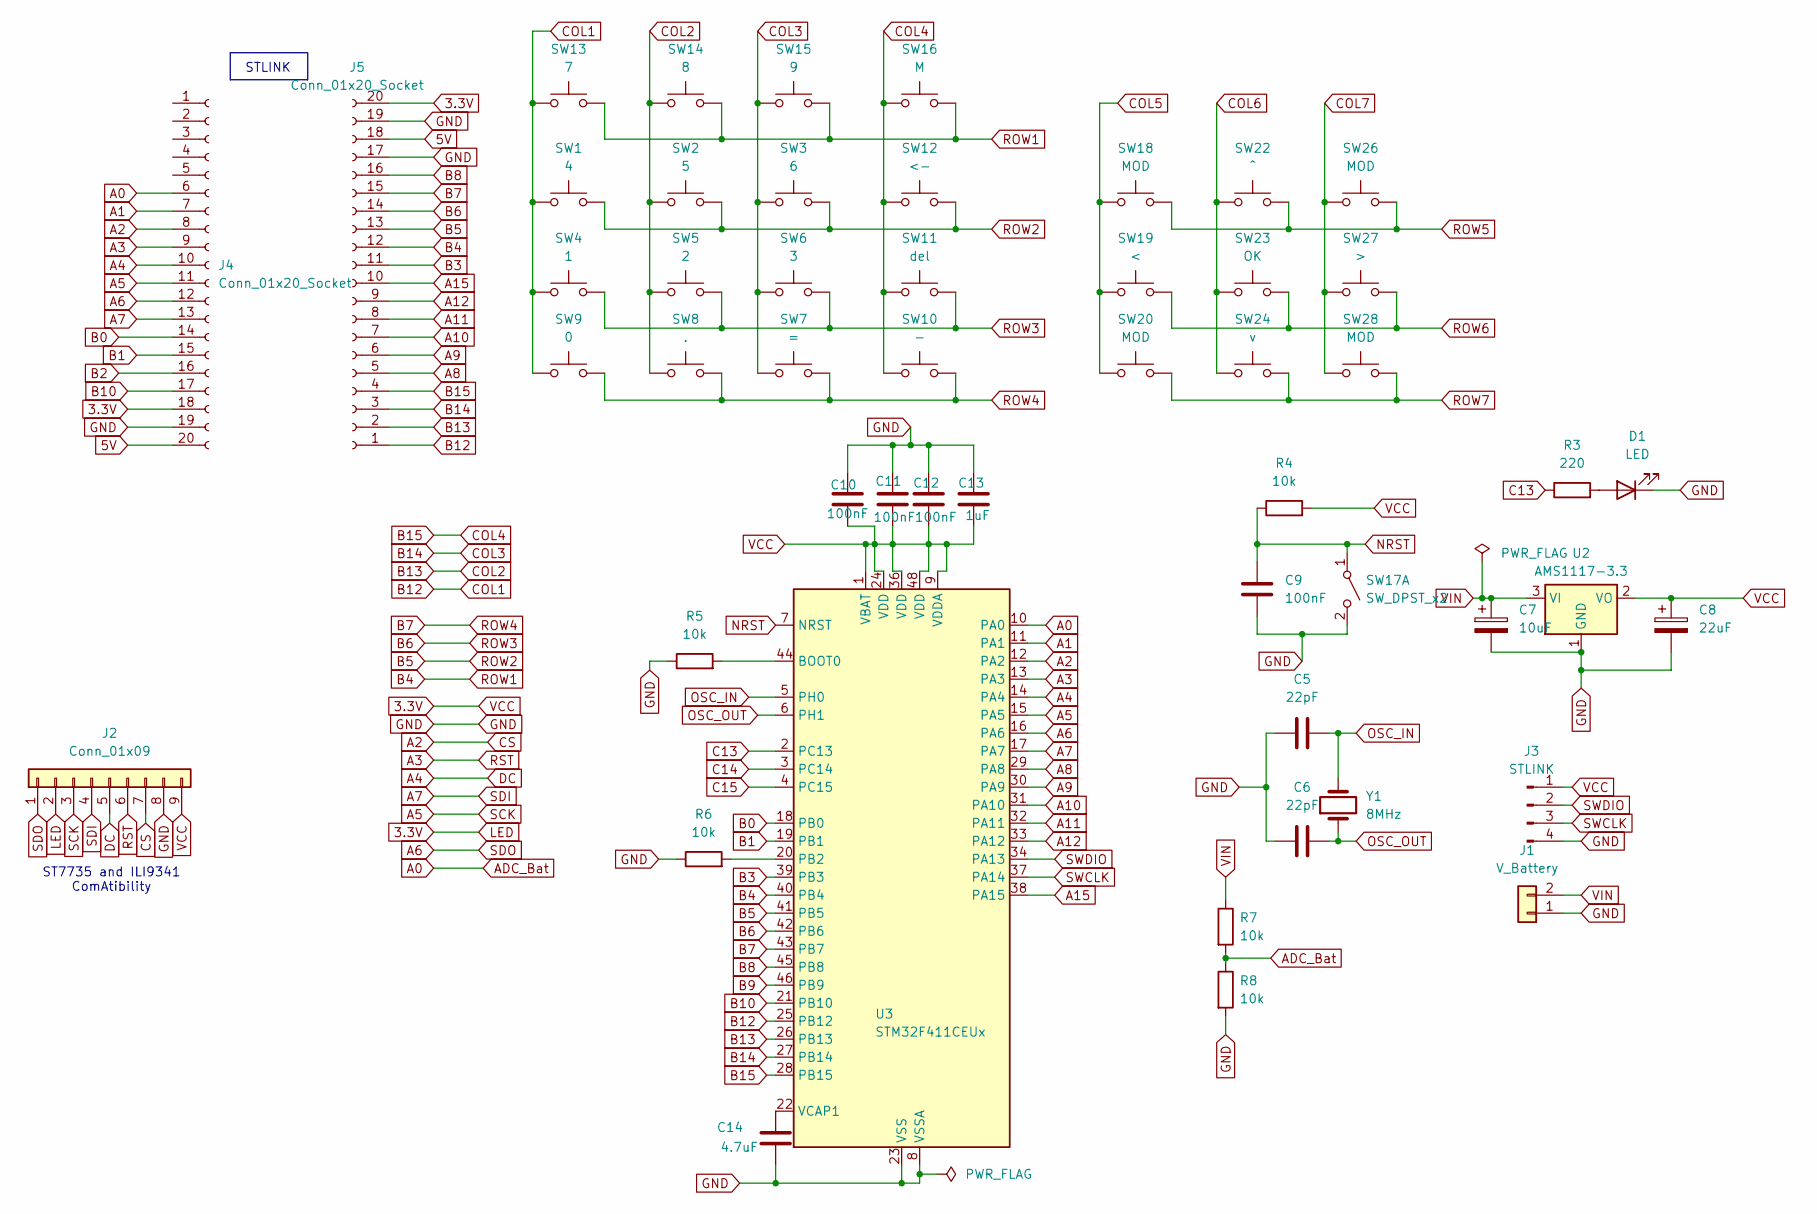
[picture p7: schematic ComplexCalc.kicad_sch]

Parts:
C5, C6: 22pF; C_0805_2012Metric_Pad1.18x1.45mm_HandSolder
C7: 10uF; C_0805_2012Metric_Pad1.18x1.45mm_HandSolder
C8: 22uF; C_0805_2012Metric_Pad1.18x1.45mm_HandSolder
C9, C10, C11, C12: 100nF; C_0805_2012Metric_Pad1.18x1.45mm_HandSolder
C13: 1uF; C_0805_2012Metric
C14: 4.7uF; C_0805_2012Metric_Pad1.18x1.45mm_HandSolder
D1: LED; LED_0603_1608Metric
J1: V_Battery; PinHeader_1x02_P2.54mm_Vertical
J2: Conn_01x09; CR2013-MI2120
J3: STLINK; PinHeader_1x04_P2.54mm_Vertical
J4, J5: Conn_01x20_Socket; PinHeader_1x20_P2.54mm_Vertical
R3: 220; R_0805_2012Metric
R4, R5, R6, R7, R8: 10k; R_0805_2012Metric
SW1: 4; SW_PUSH-12mm
SW2: 5; SW_PUSH-12mm
SW3: 6; SW_PUSH-12mm
SW4: 1; SW_PUSH-12mm
SW5: 2; SW_PUSH-12mm
SW6: 3; SW_PUSH-12mm
SW7: =; SW_PUSH-12mm
SW8: .; SW_PUSH-12mm
SW9: 0; SW_PUSH-12mm
SW10: -; SW_PUSH-12mm
SW11: del; SW_PUSH-12mm
SW12: <-; SW_PUSH-12mm
SW13: 7; SW_PUSH-12mm
SW14: 8; SW_PUSH-12mm
SW15: 9; SW_PUSH-12mm
SW16: M; SW_PUSH-12mm
SW17: SW_DPST_x2; Untitled
SW18, SW20, SW26, SW28: MOD; SW_PUSH-12mm
SW19: <; SW_PUSH-12mm
SW22: ^; SW_PUSH-12mm
SW23: OK; SW_PUSH-12mm
SW24: v; SW_PUSH-12mm
SW27: >; SW_PUSH-12mm
U2: AMS1117-3.3; SOT-223-3_TabPin2
U3: STM32F411CEUx; QFN-48-1EP_7x7mm_P0.5mm_EP5.6x5.6mm
Y1: 8MHz; Crystal_SMD_EuroQuartz_MQ2-2Pin_7.0x5.0mm

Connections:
3.3V: C8.1, C10.1, C11.1, C12.1, C13.1, J2.2, J2.9, J3.1, J4.18, J5.20, R4.2, U2.2 (VO), U3.1 (VBAT), U3.9 (VDDA), U3.24 (VDD), U3.36 (VDD), U3.48 (VDD)
5V: J4.20, J5.18
A0: J4.6, R7.2, R8.1, U3.10 (PA0)
A1: J4.7, U3.11 (PA1)
A2: J2.7, J4.8, U3.12 (PA2)
A3: J2.6, J4.9, U3.13 (PA3)
A4: J2.5, J4.10, U3.14 (PA4)
A5: J2.3, J4.11, U3.15 (PA5)
A6: J2.1, J4.12, U3.16 (PA6)
A7: J2.4, J4.13, U3.17 (PA7)
A8: J5.5, U3.29 (PA8)
A9: J5.6, U3.30 (PA9)
A10: J5.7, U3.31 (PA10)
A11: J5.8, U3.32 (PA11)
A12: J5.9, U3.33 (PA12)
A15: J5.10, U3.38 (PA15)
B0: J4.14, U3.18 (PB0)
B1: J4.15, U3.19 (PB1)
B2: J4.16
B3: J5.11, U3.39 (PB3)
B4: J5.12, SW13.2, SW14.2, SW15.2, SW16.2, U3.40 (PB4)
B5: J5.13, SW1.2, SW2.2, SW3.2, SW12.2, U3.41 (PB5)
B6: J5.14, SW4.2, SW5.2, SW6.2, SW11.2, U3.42 (PB6)
B7: J5.15, SW7.2, SW8.2, SW9.2, SW10.2, U3.43 (PB7)
B8: J5.16, U3.45 (PB8)
B9: U3.46 (PB9)
B10: J4.17, U3.21 (PB10)
B12: J5.1, SW1.1, SW4.1, SW9.1, SW13.1, U3.25 (PB12)
B13: J5.2, SW2.1, SW5.1, SW8.1, SW14.1, U3.26 (PB13)
B14: J5.3, SW3.1, SW6.1, SW7.1, SW15.1, U3.27 (PB14)
B15: J5.4, SW10.1, SW11.1, SW12.1, SW16.1, U3.28 (PB15)
C13: R3.1, U3.2 (PC13)
C14: U3.3 (PC14)
C15: U3.4 (PC15)
COL5: SW18.1, SW19.1, SW20.1
COL6: SW22.1, SW23.1, SW24.1
COL7: SW26.1, SW27.1, SW28.1
GND: C5.2, C6.2, C7.2, C8.2, C9.1, C10.2, C11.2, C12.2, C13.2, C14.2, D1.1 (K), J1.1, J2.8, J3.4, J4.19, J5.17, J5.19, R5.1, R6.1, R8.2, SW17.2 (B), U2.1 (GND), U3.8 (VSSA), U3.23 (VSS), U3.35 (VSS), U3.47 (VSS), U3.49 (VSS)
NRST: C9.2, R4.1, SW17.1 (A), U3.7 (NRST)
unnamed: D1.2 (A), R3.2
unnamed: R5.2, U3.44 (BOOT0)
unnamed: R6.2, U3.20 (PB2)
unnamed: C14.1, U3.22 (VCAP1)
OSC_IN: C5.1, U3.5 (PH0), Y1.2
OSC_OUT: C6.1, U3.6 (PH1), Y1.1
ROW5: SW18.2, SW22.2, SW26.2
ROW6: SW19.2, SW23.2, SW27.2
ROW7: SW20.2, SW24.2, SW28.2
SWCLK: J3.3, U3.37 (PA14)
SWDIO: J3.2, U3.34 (PA13)
VIN: C7.1, J1.2, R7.1, U2.3 (VI)

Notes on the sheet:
STLINK
ST7735 and ILI9341 ComAtibility

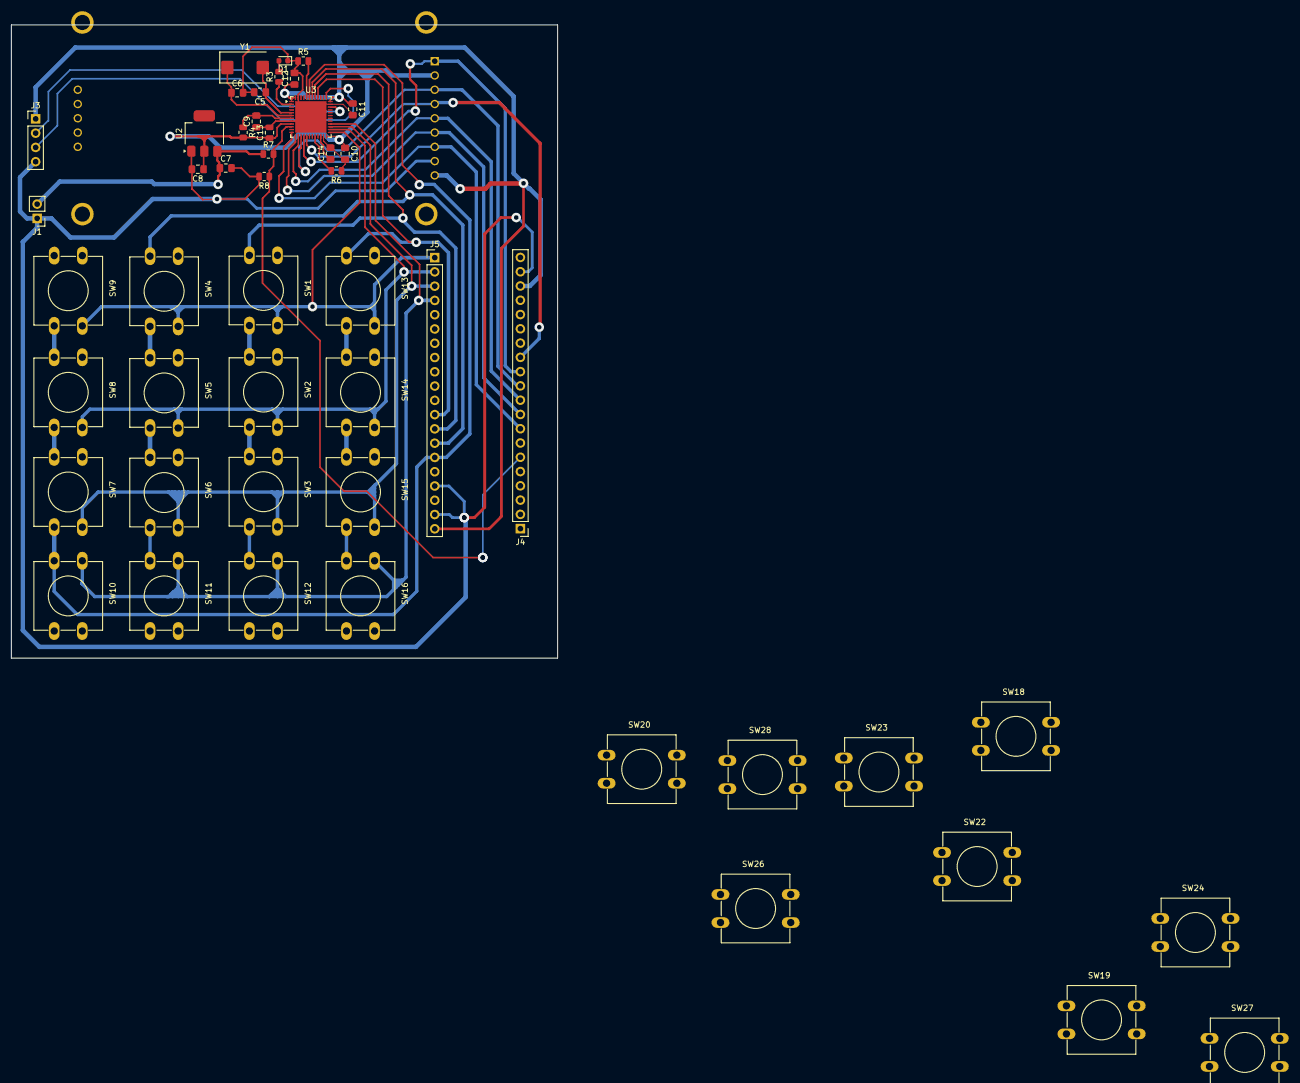
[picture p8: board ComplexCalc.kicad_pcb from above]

Board: 2 copper layers, 97.2 x 112.7 mm, 50 parts (1 on the bottom side), 47 nets.

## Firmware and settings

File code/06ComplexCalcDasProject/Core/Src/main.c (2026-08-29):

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
/* Includes ------------------------------------------------------------------*/
#include "main.h"

/* USER CODE BEGIN Includes */
#include "TFT_Screen.h"
#include "HALTecMat4x4.h"
#include "fonts.h"
#include "display_ui.h"
#include <stdlib.h>
#include <string.h>
#include "ComplexGJ.h"
/* USER CODE END Includes */

SPI_HandleTypeDef hspi1;

/* USER CODE BEGIN PV */
uint8_t level = 0 ;

// Buffer
#define BUFFER_SIZE 16
uint8_t index_Var = 0;
char buffer[BUFFER_SIZE];
uint8_t navigating = 0;
// Matriz y tama;o de matriz
uint8_t matSize;
cplx A[N_MAX][N_MAX] = {0};
cplx b[N_MAX] = {0};
cplx x[N_MAX] = {0};

// Variables de control de pantalla
uint8_t needsRedraw = 1;
uint8_t editingReal = 1; // 1 = editando real, 0 = editando imaginario
double real = 0.0, imag = 0.0;

/* USER CODE END PV */

void SystemClock_Config(void);
static void MX_GPIO_Init(void);
static void MX_SPI1_Init(void);
/* USER CODE BEGIN PFP */
uint8_t readPad(char *);

/* USER CODE END PFP */

/**
  * @brief  The application entry point.
  * @retval int
  */
int main(void)
{

  /* MCU Configuration--------------------------------------------------------*/

  /* Reset of all peripherals, Initializes the Flash interface and the Systick. */
  HAL_Init();

  /* Configure the system clock */
  SystemClock_Config();

  /* Initialize all configured peripherals */
  MX_GPIO_Init();
  MX_SPI1_Init();
  /* USER CODE BEGIN 2 */
 
	char *keypress = NULL;
	char *endptr;
	uint8_t messageReady = 1;
	// Matriz
	uint8_t colMat = 0, rowMat = 0;
	double real, imag = 0.0;
	memset(buffer, 0, sizeof(buffer));
  __HAL_SPI_ENABLE(&hspi1);

    Screen_Init();
    initTheme();
  /* USER CODE END 2 */

  /* Infinite loop */
  /* USER CODE BEGIN WHILE */
  while (1)
  {
    /* USER CODE END WHILE */

    /* USER CODE BEGIN 3 */
    switch (level){
    case 0:
        // Dibujar pantalla solo cuando sea necesario
        if(needsRedraw) {
            drawLevel0();
            needsRedraw = 0;
        }
        
        keypress = gotKey();
        messageReady = readPad(keypress);
        
        if(messageReady == 0){
            // Actualizar solo el buffer en pantalla

            break;
        }

        // Conversión a entero
        matSize = (uint8_t)strtol(buffer, &endptr, 10);

        if ((endptr == buffer) || (matSize == 0)) {
            level = 0;
            needsRedraw = 1;
        }
        else if(matSize > N_MAX ) matSize = N_MAX;
        else if(matSize<2) matSize = 2;

        if(matSize >= 2 && matSize <= N_MAX) {
        	drawLevel0();


        	memset(buffer, 0, sizeof(buffer));
            index_Var = 0;
            colMat = 0;
            rowMat = 0;
            editingReal = 1;
            level = 1;
            needsRedraw = 1;
        }

        break;

    case 1:
        if(needsRedraw) {
            drawLevel1(colMat, rowMat);
            needsRedraw = 0;
        }
        
        keypress = gotKey();
        messageReady = readPad(keypress);
        
		// Si se presionó una tecla pero no es un mensaje completo
		if(messageReady == 2) {
			// Buffer cambió (se agregó/borró un dígito)
			needsRedraw = 1;
			break;
		}
		
		
		// Si no hay nada en el buffer, permitir navegación
        if(index_Var == 0 && navigating) {
            switch (*keypress){
                case 'W':
                    if(colMat > 0) colMat--;
                    needsRedraw = 1;
                    break;
                case 'B':
                    if(colMat < matSize - 1) colMat++;
                    needsRedraw = 1;
                    break;
                case 'L':
                    if(rowMat > 0) rowMat--;
                    needsRedraw = 1;
                    break;
                case 'R':
                    if(rowMat < matSize) rowMat++;
                    needsRedraw = 1;
                    break;            }
            break;
        }
        
        // Si hay mensaje (se presionó un número o tecla especial)
        if(messageReady == 1) {
            if(*keypress == '=') {
                if(editingReal) {
                    // Termina ingreso de parte real, pasa a imaginario
                    if(index_Var > 0) {
                        // Solo guardar si hay datos en el buffer
                        real = strtod(buffer, &endptr);
                        if(rowMat < matSize) A[colMat][rowMat].r = real;
                        else b[colMat].r = real;
                    }
                    memset(buffer, 0, sizeof(buffer));
                    index_Var = 0;
                    editingReal = 0;
                    needsRedraw = 1;
                } else {
                    // Termina ingreso de parte imaginaria, guarda y avanza
                    if(index_Var > 0) {
                        // Solo guardar si hay datos en el buffer
                        imag = strtod(buffer, &endptr);
                        if(rowMat < matSize) A[colMat][rowMat].i = imag;
                        else b[colMat].i = imag;
                    }
                    // Reset y avanzar
                    memset(buffer, 0, sizeof(buffer));
                    index_Var = 0;
                    editingReal = 1;
                    real = 0.0;
                    imag = 0.0;
                    // Avanzar a siguiente celda (por COLUMNAS primero)
                    rowMat++;
                    if(rowMat > matSize) {
                        rowMat = 0;
                        colMat++;
                    }
                    // Si terminamos, ir a resolver
                    if(colMat >= matSize) {
                        level = 2;
                    }
                    needsRedraw = 1;
                }
            } else if(*keypress == 'I') {
                // Tecla I: terminar parte real y pasar a imaginaria
                if(editingReal) {
                    if(index_Var > 0) {
                        real = strtod(buffer, &endptr);
                        if(rowMat < matSize) A[colMat][rowMat].r = real;
                        else b[colMat].r = real;
                    }
                    memset(buffer, 0, sizeof(buffer));
                    index_Var = 0;
                    editingReal = 0;
                    needsRedraw = 1;
                }
            }
        }
        break;

    case 2:
        // Resolver el sistema
        int success = solve_complex_system(matSize, A, b, x);
        drawLevel2(success == 0);
        
        // Esperar tecla para volver
        messageReady = 0;
        while(!(messageReady)){
            keypress = gotKey();
            messageReady = readPad(keypress);
        }
        
        // // Reset para nuevo sistema - limpiar matrices
        // memset(A, 0, sizeof(A));
        // memset(b, 0, sizeof(b));
        // memset(x, 0, sizeof(x));
        level = 0;
         matSize = 0;
        colMat = 0;  // Reset matrix position
        rowMat = 0;  // Reset matrix position
        memset(buffer, 0, sizeof(buffer));
        index_Var = 0;
        editingReal = 1;
        needsRedraw = 1;
        break;

		}
  }
  /* USER CODE END 3 */
}

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
/* USER CODE BEGIN 4 */


uint8_t readPad(char *keypress){

    if (keypress == NULL) return 0;
    char key = *keypress;

    // Handle control keys
    if (key == '=') {
        /*if (level < 2) level++;
        if (level == 2) level--;*/
        return 1;
    }
	if (*keypress == '-') {
    // Only allow '-' as the first character in the buffer
    if (index_Var == 0) {
        buffer[index_Var++] = '-';
        return 2;} 
	else return 0; // Ignore if not at start
	}
    if (key == 'T') { // Back
        if (level > 0) level--; 
        memset(buffer, 0, sizeof(buffer));
        index_Var = 0;
        return 2;
    }
    if (key == 'D') {
        if (index_Var > 0) { // Backspace
            index_Var--;
            buffer[index_Var] = 0;
        }
        return 2;
    }
    if (key == 'I') {
        return 1;
    }
    if (key == 'F') { // Alt Mode
        navigating ^= 1;
        return 2;
    }
    if (key == 'S'){ // Solve
        level = 2; 
        return 2;
    }
    if (key == 'P') {
        toggleTheme(); //Pink Mode
        needsRedraw = 1;
        return 2;
    }

    // Handle numbers and dot
    if ((key >= '0' && key <= '9') || key == '.') {
        if (index_Var < BUFFER_SIZE) {
            buffer[index_Var++] = key;
        }
        return 2;
    }

    // Unknown key
    return 0;
					}

/* USER CODE END 4 */
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


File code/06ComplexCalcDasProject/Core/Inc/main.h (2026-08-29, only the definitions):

#define SCREEN_CS_Pin GPIO_PIN_2
#define SCREEN_CS_GPIO_Port GPIOA
#define SCREEN_RST_Pin GPIO_PIN_3
#define SCREEN_RST_GPIO_Port GPIOA
#define SCREEN_D_C_Pin GPIO_PIN_4
#define SCREEN_D_C_GPIO_Port GPIOA
#define COL1_Pin GPIO_PIN_12
#define COL1_GPIO_Port GPIOB
#define COL2_Pin GPIO_PIN_13
#define COL2_GPIO_Port GPIOB
#define COL3_Pin GPIO_PIN_14
#define COL3_GPIO_Port GPIOB
#define COL4_Pin GPIO_PIN_15
#define COL4_GPIO_Port GPIOB
#define ROW1_Pin GPIO_PIN_4
#define ROW1_GPIO_Port GPIOB
#define ROW2_Pin GPIO_PIN_5
#define ROW2_GPIO_Port GPIOB
#define ROW3_Pin GPIO_PIN_6
#define ROW3_GPIO_Port GPIOB
#define ROW4_Pin GPIO_PIN_7
#define ROW4_GPIO_Port GPIOB

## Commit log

2026-08-29 feat : Cloned for DasReyx
    [ComplexCalc.kicad_pcb, ComplexCalc.kicad_sch]
2026-08-29 Falta conectar algunas cosas y las resistencias con el ADC
    [ComplexCalc.kicad_pcb, ComplexCalc.kicad_sch]
2026-08-29 Vias mas grandes
    [ComplexCalc.kicad_pcb]
2026-09-02 Sigue faltando el adc
    [ComplexCalc.kicad_pcb]
2026-09-02 Con el readme
2026-09-03 Rewrite README to match the actual repo
    The previous README described a fabricated dual-platform ("BlackPill"/
    "RayPill") setup, a UART/serial interface, 10x10 double-precision
    solving, and links to files/folders that don't exist in this repo
    (../LICENSE, ../README_GENERAL.md, HW Files Schematic & Design/) or
    point to the wrong repo (software repo's Issues). Replaced it with an
    accurate description grounded in the actual code: single STM32F411
    custom PCB, ILI9341 TFT + 4x4 keypad, no UART needed at runtime,
    Gauss-Jordan solver at N_MAX=4 with float precision, and real build
    instructions (STM32CubeIDE or the project's own CMake presets). Notes
    the PCB routing is still in progress rather than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
2026-09-03 Fix regulator part number in README: AMS1117-3.3, not NCP1117-3.3
    Verified against the actual schematic (U2's Value field).
2026-09-03 docs: add collaborator credits to code and design mini-readmes
    Credit das for the firmware, and das/robertoloro/IKGB for their
    respective roles on the PCB design.
2026-09-04 Fixxed capacitors values C14,C9 and VBAT to 3.3 V
    [ComplexCalc.kicad_pcb, ComplexCalc.kicad_sch]
2026-09-05 ADC trace connected
    [ComplexCalc.kicad_pcb, ComplexCalc.kicad_sch]

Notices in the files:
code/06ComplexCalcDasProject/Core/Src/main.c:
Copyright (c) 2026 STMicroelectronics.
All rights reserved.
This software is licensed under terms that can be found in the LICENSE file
